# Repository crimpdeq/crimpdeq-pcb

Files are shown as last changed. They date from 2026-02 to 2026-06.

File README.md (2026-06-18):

# Crimpdeq PCB

KiCad PCB design for Crimpdeq. See the [Crimpdeq book](https://crimpdeq.com/) for more details on the project!

## PCB

The PCB design is located under `pcb/crimpdeq/` and was created using KiCad. It is a two-layer board based on the [Rust ESP Board](https://github.com/esp-rs/esp-rust-board). This design removes unused sensors from the original board and adds the necessary components for this project.

PCB

The PCB was sponsored by [PCBWay](https://www.pcbway.com/), thank you! Working with them was incredibly easy and fast, and the resulting boards are high quality.

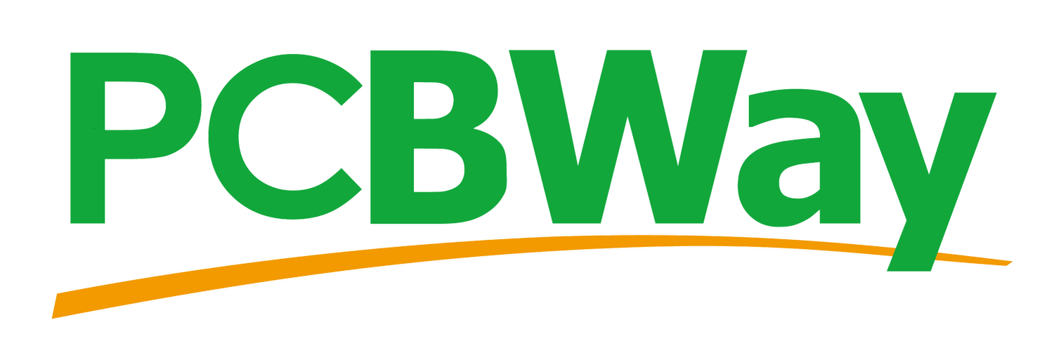
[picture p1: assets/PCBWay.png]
PCBWay (https://www.pcbway.com/)


## License

This repository is source-available for personal and educational use only.

Commercial manufacture, sale of PCBs, sale of 3D-printed cases, kits, or assembled Crimpdeq devices requires prior written permission.

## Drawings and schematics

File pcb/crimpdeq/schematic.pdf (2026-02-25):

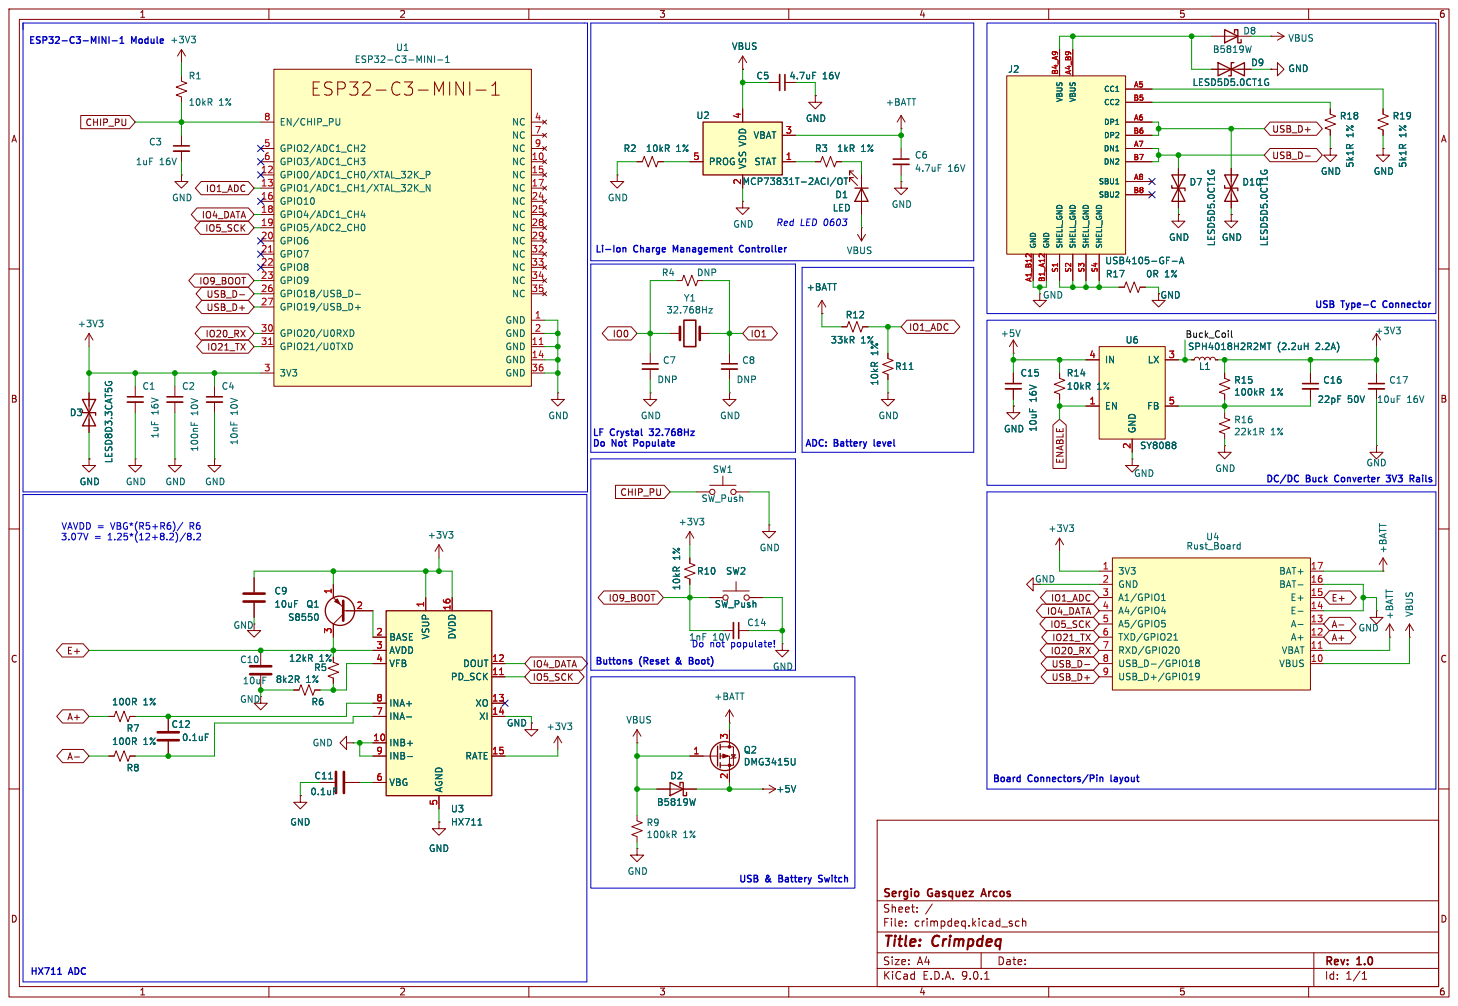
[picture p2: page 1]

2 VBAT 3 STAT 1 U2 MCP73831T-2ACI/OT VBUS

2 VBAT 3 STAT 1 VBUS GND

File: crimpdeq.kicad_sch Sheet: / Sergio Gasquez Arcos GND

5 DVDD 16 DOUT 12 PD_SCK 11 XO 13 XI 14 RATE 15 U3 HX711

5 DVDD 16 DOUT 12 PD_SCK 11 XO 13 XI 14 RATE 15

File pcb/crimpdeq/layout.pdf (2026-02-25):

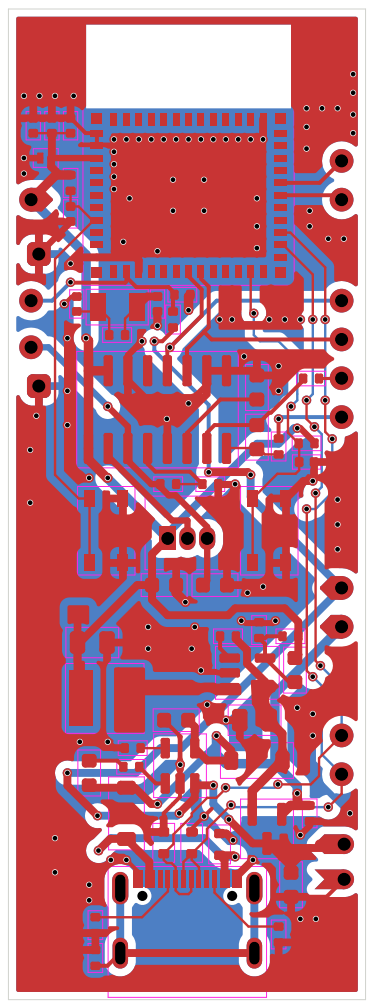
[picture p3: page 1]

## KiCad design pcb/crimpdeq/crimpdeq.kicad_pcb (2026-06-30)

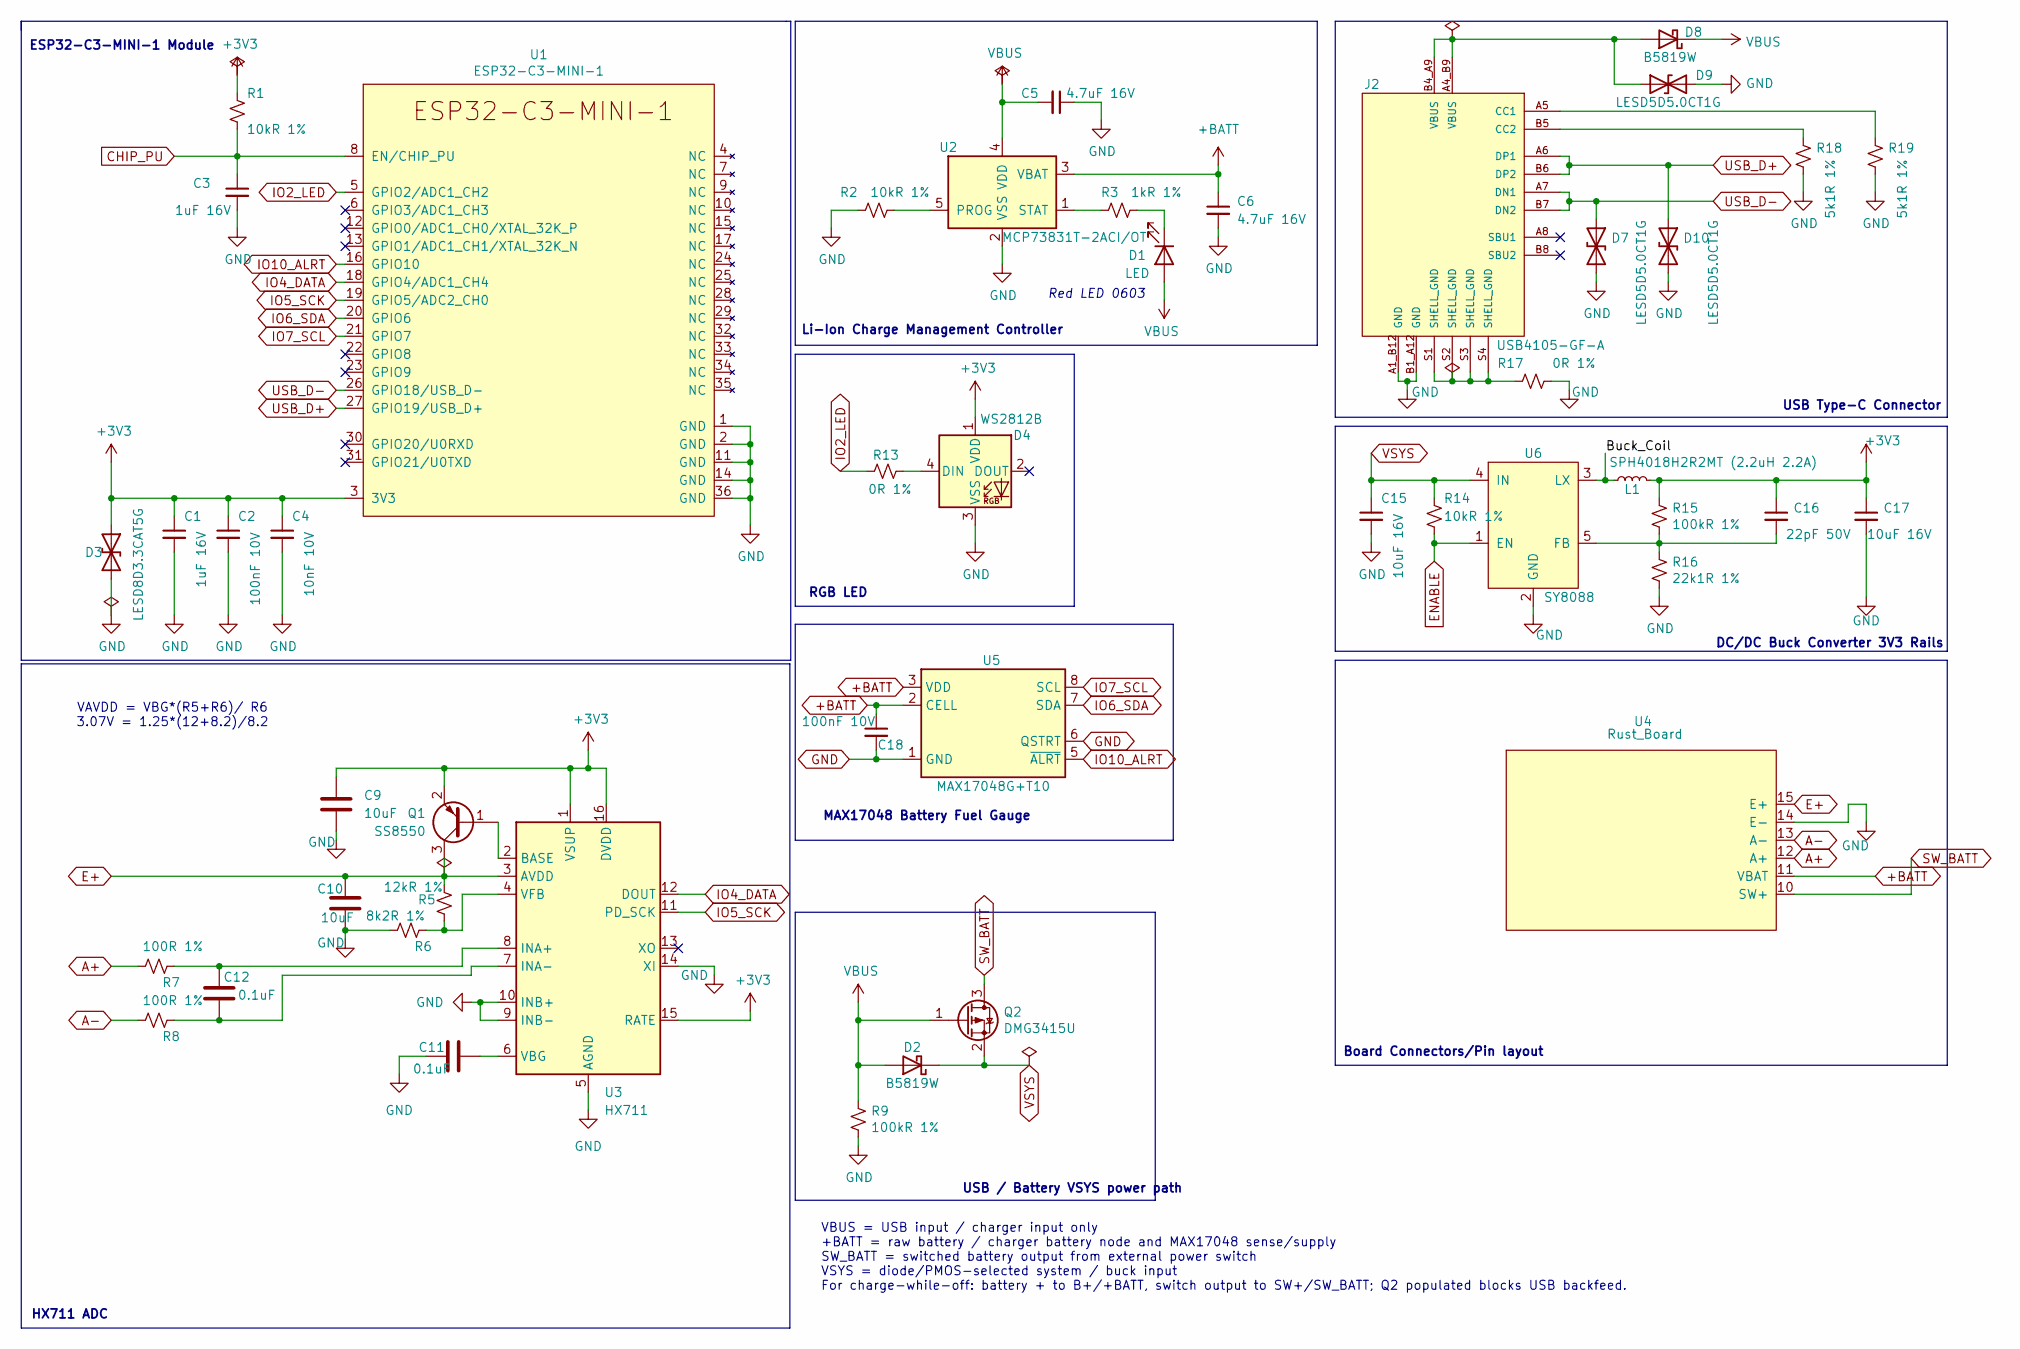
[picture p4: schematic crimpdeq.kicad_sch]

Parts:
C1, C3: 1uF 16V; C_0402_1005Metric; LCSC C52923
C2: 100nF 10V; C_0402_1005Metric; LCSC C1525
C4: 10nF 10V; C_0402_1005Metric; LCSC C15195
C5, C6: 4.7uF 16V; C_0603_1608Metric; LCSC C19666
C9, C10: 10uF; C_0603_1608Metric
C11, C12: 0.1uF; C_0603_1608Metric
C15, C17: 10uF 16V; C_0805_2012Metric; LCSC C15850
C16: 22pF 50V; C_0603_1608Metric; LCSC C1653
C18: 100nF 10V; C_0402_1005Metric
D1: LED; LED_0603_1608Metric; LCSC C2286
D2, D8: B5819W; D_SOD-123; LCSC C8598
D3: LESD8D3.3CAT5G; D_SOD-882; LCSC C172409
D4: WS2812B; LED_WS2812B_PLCC4_5.0x5.0mm_P3.2mm
D7, D9, D10: LESD5D5.0CT1G; D_SOD-523; LCSC C383211
J2: USB4105-GF-A; GCT_USB4105-GF-A; PARTREV A3; LCSC C165948
L1: SPH4018H2R2MT (2.2uH 2.2A); L_Bourns-SRN4018; LCSC C370436
Q1: SS8550; SOT-23
Q2: DMG3415U; SOT-23; LCSC C96616
R1, R2, R14: 10kR 1%; R_0402_1005Metric; LCSC C25744
R3: 1kR 1%; R_0402_1005Metric; LCSC C11702
R5: 12kR 1%; R_0402_1005Metric; LCSC C25741
R6: 8k2R 1%; R_0402_1005Metric; LCSC C25741
R7, R8: 100R 1%; R_0402_1005Metric; LCSC C25741
R9, R15: 100kR 1%; R_0402_1005Metric; LCSC C25741
R13: 0R 1%; R_0402_1005Metric; LCSC C25744
R16: 22k1R 1%; R_0402_1005Metric; LCSC C43473
R17: 0R 1%; R_0402_1005Metric; LCSC C17168
R18, R19: 5k1R 1%; R_0402_1005Metric; LCSC C25905
U1: ESP32-C3-MINI-1; LCSC C2838502
U2: MCP73831T-2ACI/OT; SOT-23-5; LCSC C424093
U3: HX711; SOP-16_3.9x9.9mm_P1.27mm
U4: Rust_Board
U5: MAX17048G+T10; TDFN-8-1EP_2x2mm_P0.5mm_EP0.8x1.2mm
U6: SY8088; SOT-23-5; LCSC C479072

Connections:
+3V3: C1.1, C2.1, C4.1, C9.1, C16.1, C17.1, D3.1 (A1), D4.1 (VDD), L1.2, Q1.2 (E), R1.1, R15.1, U1.3 (3V3), U3.1 (VSUP), U3.15 (RATE), U3.16 (DVDD)
+BATT: C6.1, C18.1, U2.3 (VBAT), U4.11 (VBAT), U5.2 (CELL), U5.3 (VDD); also elsewhere on the board
/Buck_Coil: L1.1, U6.3 (LX)
A+: R7.2, U4.12 (A+); also elsewhere on the board
A-: R8.2, U4.13 (A-); also elsewhere on the board
CHIP_PU: C3.1, R1.2, U1.8 (EN/CHIP_PU)
E+: C10.1, Q1.3 (C), R5.1, U3.3 (AVDD), U4.15 (E+); also elsewhere on the board
ENABLE: R14.2, U6.1 (EN)
GND: C1.2, C2.2, C3.2, C4.2, C5.1, C6.2, C9.2, C10.2, C11.1, C15.2, C17.2, C18.2, D3.2 (A2), D4.3 (VSS), D7.2 (A2), D9.2 (A2), D10.2 (A2), J2.A1_B12 (GND), J2.B1_A12 (GND), R2.1, R6.2, R9.2, R16.2, R17.2, R18.2, R19.2, U1.1 (GND), U1.2 (GND), U1.11 (GND), U1.14 (GND), U1.36 (GND), U2.2 (VSS), U3.5 (AGND), U3.9 (INB-), U3.10 (INB+), U3.14 (XI), U4.14 (E-), U5.1 (GND), U5.4 (GND), U5.6 (QSTRT), U5.9 (GND), U6.2 (GND); also elsewhere on the board
IO2_LED: R13.1, U1.5 (GPIO2/ADC1_CH2)
IO4_DATA: U1.18 (GPIO4/ADC1_CH4), U3.12 (DOUT)
IO5_SCK: U1.19 (GPIO5/ADC2_CH0), U3.11 (PD_SCK)
IO6_SDA: U1.20 (GPIO6), U5.7 (SDA)
IO7_SCL: U1.21 (GPIO7), U5.8 (SCL)
IO10_ALRT: U1.16 (GPIO10), U5.5 (~ALRT)
unnamed: D1.1 (K), R3.2
unnamed: D4.4 (DIN), R13.2
unnamed: D8.2 (A), D9.1 (A1), J2.A4_B9 (VBUS), J2.B4_A9 (VBUS)
unnamed: J2.A5 (CC1), R19.1
unnamed: J2.B5 (CC2), R18.1
unnamed: J2.S1 (SHELL_GND), J2.S2 (SHELL_GND), J2.S3 (SHELL_GND), J2.S4 (SHELL_GND), R17.1
unnamed: Q1.1 (B), U3.2 (BASE)
unnamed: R2.2, U2.5 (PROG)
unnamed: R3.1, U2.1 (STAT)
unnamed: C12.1, R7.1, U3.8 (INA+)
unnamed: C12.2, R8.1, U3.7 (INA-)
unnamed: C11.2, U3.6 (VBG)
unnamed: R5.2, R6.1, U3.4 (VFB)
unnamed: C16.2, R15.2, R16.1, U6.5 (FB)
SW_BATT: Q2.3 (D), U4.10 (SW+); also elsewhere on the board
USB_D+: D10.1 (A1), J2.A6 (DP1), J2.B6 (DP2), U1.27 (GPIO19/USB_D+)
USB_D-: D7.1 (A1), J2.A7 (DN1), J2.B7 (DN2), U1.26 (GPIO18/USB_D-)
VBUS: C5.2, D1.2 (A), D2.2 (A), D8.1 (K), Q2.1 (G), R9.1, U2.4 (VDD)
VSYS: C15.1, D2.1 (K), Q2.2 (S), R14.1, U6.4 (IN)

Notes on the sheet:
USB Type-C Connector
VAVDD = VBG*(R5+R6)/ R6 3.07V = 1.25*(12+8.2)/8.2
Board Connectors/Pin layout
Li-Ion Charge Management Controller
USB / Battery VSYS power path
MAX17048 Battery Fuel Gauge
Red LED 0603
HX711 ADC
ESP32-C3-MINI-1 Module
RGB LED
DC/DC Buck Converter 3V3 Rails
VBUS = USB input / charger input only +BATT = raw battery / charger battery node and MAX17048 sense/supply SW_BATT = switched battery output from external power switch VSYS = diode/PMOS-selected system / buck input For charge-while-off: battery + to B+/+BATT, switch output to SW+/SW_BATT; Q2 popula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

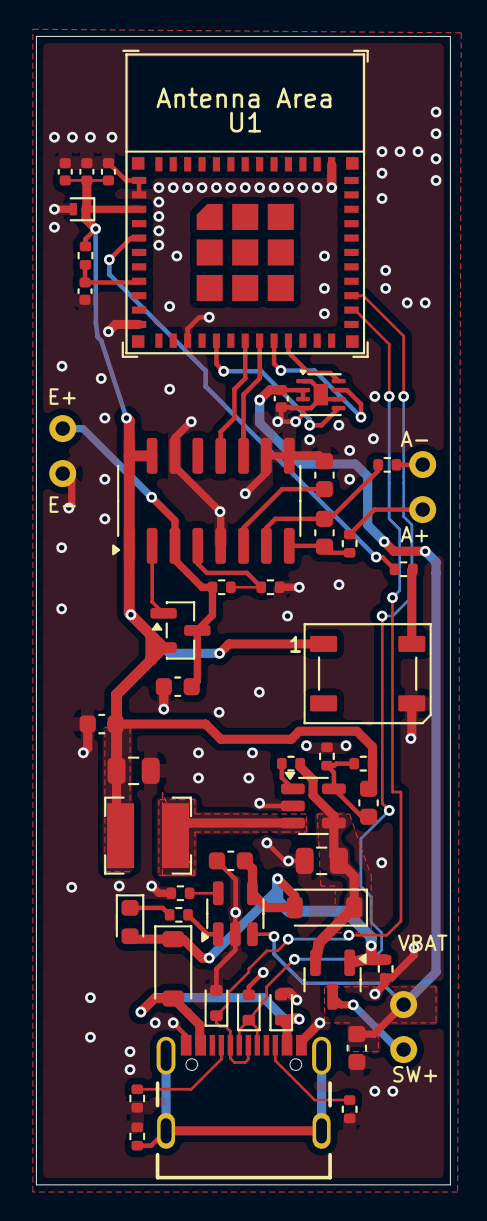
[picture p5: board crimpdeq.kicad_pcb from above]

Board: 2 copper layers, 23.0 x 63.8 mm, 48 parts (0 on the bottom side), 34 nets.

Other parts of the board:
J3: Loadcell_Pads; External_Cable_Pads_Left
J4: Power_Sense_Pads; External_Cable_Pads_Right

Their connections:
+BATT: J4.3 (VBAT); also elsewhere on the board
A+: J4.2 (A+); also elsewhere on the board
A-: J4.1 (A-); also elsewhere on the board
E+: J3.1 (E+); also elsewhere on the board
GND: J3.2 (E-); also elsewhere on the board
SW_BATT: J4.4 (SW+); also elsewhere on the board

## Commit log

2026-02-17 docs: Add PCB results
2026-02-25 Add GHA checks (#6)
    * feat: Rename hardware folder to pcb
    * feat: Initial 3D models
    * feat: Add switch and rails to avoid components moving
    * feat: Add "crimpdeq" and show_lid variable
    * feat: Add CAD ci
    * feat: Round corners
    * feat: Improvements and cleanups
    * feat: Add LED and better fixations for pcb
    * feat: Update switch to KD1
    * feat: Use only 2 notches and short guide for the loadcell
    * feat: Use KCD11 instead of KCD1 and add a dimensions file to reduce duplication
    * ci: Add GHA workflows
    * feat: Make LED hole bigger, update battery thickness, remove duplication of dimensions
    * feat: Make usb-c hole a bit bigger
    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
    [crimpdeq-B_Cu.gbr, crimpdeq-B_Mask.gbr, crimpdeq-B_Paste.gbr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]
2026-03-12 fix: add assembly notes for manufacturing
    [crimpdeq.kicad_pcb, crimpdeq.kicad_sch]
2026-03-12 Ignore lib_footprint issues/mismatches (#10)
    * ci: Ignore lib_footprint issues/mismatches
    * fix: resolve KiCad ERC and DRC failures
    * ci: fail KiCad checks only on error-level violations
    [crimpdeq.kicad_sch]
2026-03-12 ci: Add adinitonal notes on bom
2026-04-09 ci: format release bom with assembly notes
2026-04-10 fix: switch Q1 to SOT-23 SS8550
    [crimpdeq.kicad_pcb, crimpdeq.kicad_sch]
2026-04-10 revert: switch Q1 to SOT-23 SS8550
    [crimpdeq.kicad_pcb, crimpdeq.kicad_sch]
2026-04-11 fix: switch Q1 to SOT-23 SS8550 (#13)
    * fix: switch Q1 to SOT-23 SS8550
    * fix: add Q1 copper keepout for KiCad 9 CI
    [crimpdeq.kicad_pcb, crimpdeq.kicad_sch]
2026-04-13 fix: align release bom generation with local output
2026-06-30 Revision 2 (#15)
    * Tim U4 pads and reroute board (#14)
    * fix: trim U4 pads and reroute board
    * fix: use KiCad 10 in workflows
    * fix: use published KiCad 10 action tag
    * fix: remove unused rtc crystal option
    * fix: allow battery charging while powered off
    * ci: add fab-friendly gerber release archive
    * refactor: clarify system power rail naming
    * refactor: tighten usb protection breakout routing
    * fix: adjust Q2 and C6 placement
    * fix: remove unused rust board pads
    * feat: Add rbg led and route it
    * fix: resolve schematic and layout rule violations
    * fix: allow charging while switched off
    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
    [crimpdeq.kicad_pcb, crimpdeq.kicad_sch]
2026-06-30 fix: allow USB-C connector manufacturing clearances (#17)
2026-07-09 ci: include soldermask in release gerbers
2026-10-13 Revision 3 (#26)
    * Reorganize PCB designs and add crimpdeq-v2-nano (25x26mm 4-layer compact board)
    Moves the original design to pcb/designs/crimpdeq-v2/ so each PCB
    package can live in its own versioned directory, and adds
    pcb/designs/crimpdeq-v2-nano/: a 4-layer, 25 x 26 mm redesign
    (~56% smaller board area than crimpdeq-v2: 1467.4 mm2 -> 650.0 mm2)
    with the ESP32 antenna and status LED both moved to the back and
    USB/HX711 kept on the front.
    - Electrically identical to crimpdeq-v2: same 48-component BOM,
    same 197-pad netlist, 0 changed nets
    - Passes KiCad DRC (0 violations, 0 unconnected)
    - Validated on JLCPCB's website DFM checker: all danger-level
    findings were reviewed and resolved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
2026-10-19 ci: let KiCad container write release assembly files (#31)
2026-11-09 fix: mark the D1 cathode with the closed silkscreen end
    The plain 0603 footprint closes the outline at pin 1, the LED anode. PCBWay
    read the closed end as the cathode and fitted D1 reversed. led0603 has the same
    pads and 3D model, with the outline closed at the cathode.
2026-11-13 refactor: remove the KiCad design
    The tscircuit design (crimpdeq/crimpdeq-tscircuit) replaces it as the canonical PCB. The KiCad revisions stay available at their release tags (v1.0.0 to v3.0.0).
2026-11-13 docs: present the tscircuit design as PCB V4
2026-11-13 ci: name release files after crimpdeq-pcb
2026-11-13 Merge pull request #35 from crimpdeq/fix/silkscreen-labels
    fix: cut the board under the antenna and make the silkscreen legible
2026-11-13 fix: switch the status LED supply off in deep sleep
    D4 sat on 3V3 behind a 0 ohm link, so its WS2812 idle current flowed in
    deep sleep. Replace R24 with a P-MOSFET high-side switch (Q3, NTK3139P):
    IO2 low powers D4, and a 100k gate pull-up (R26) holds it off in deep
    sleep and reset, doubling as the pull-up Espressif recommends for the
    IO2 strapping pin. LED data moves to IO20 (RXD0).
    Firmware must drive IO2 low to light D4, release it before deep sleep
    and keep the data line low while D4 is off.
    Refs #30
